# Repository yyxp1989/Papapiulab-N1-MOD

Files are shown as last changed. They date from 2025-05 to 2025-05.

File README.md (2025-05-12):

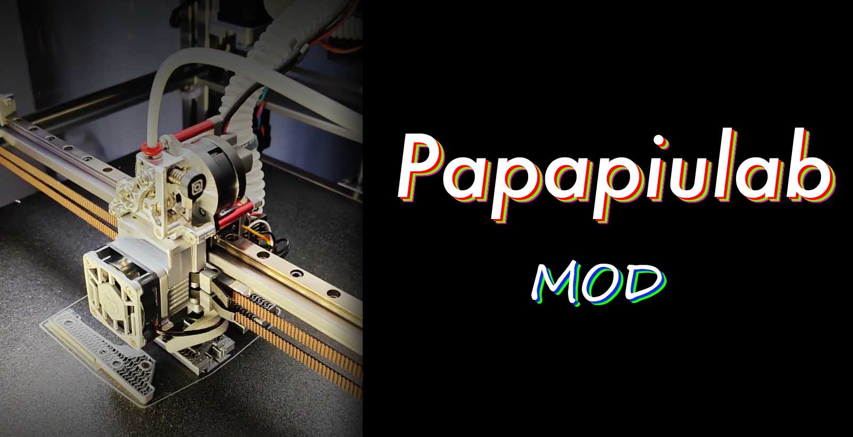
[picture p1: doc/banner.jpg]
papapiulab mod
<p align="center"></a></p>

# Papapiulab N1 MOD
- Papapiulab N1机型定制设计的第三方功能扩展组件
- 如果你喜欢请点击右上星星star收藏^^

# MOD LIST
2025/05/11 [舵机清洁工具](https://github.com/yyxp1989/Papapiulab-N1-MOD/tree/main/Servo_Clear%E8%88%B5%E6%9C%BA%E6%B8%85%E6%B4%81%E5%B7%A5%E5%85%B7)

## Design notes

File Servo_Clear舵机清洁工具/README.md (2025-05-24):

# 准备元件
- 1.微雪树莓派RP2040-Zero [TB](https://item.taobao.com/item.htm?id=658812037267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)
- 2.MG996R或20KG 180度舵机[TB](https://item.taobao.com/item.htm?id=583846405061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)
- 3.轻触开关12x12x5 [TB](https://detail.tmall.com/item.htm?id=14982998994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)
- 4.M3*20~25薄头内六角螺丝<br>
- 5.AWG30左右软电线 红黑黄绿蓝等<br>
- 6.xh2.54 3P公头或插座<br>
- 7.xh2.54 2P连接头<br>
- 8.usb3.0一母二公双头辅助供电线[TB](https://item.taobao.com/item.htm?id=876203533245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)
- 9.25T-6mm全长58mm金属舵机臂 [TB](https://item.taobao.com/item.htm?id=535025013284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)
- 10.A1 mini喷嘴硅胶擦嘴耗材刷[TB](https://item.taobao.com/item.htm?id=821254137525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)
- 11.热熔螺母M3 5个 + M3*8螺丝
- 12.M4*14内六角+4040型材T型或弹片螺母

# RP2040 klipper固件制作
- 1.SSH进入上位机 cd klipper/ <br>
- 2.输入 make clean<br>
- 3.输入 make menuconfig<br>
- 4.选择并调整菜单内容<br>
    - Micro-controller Architecture (Raspberry Pi RP2040/RP235x)  ---><br>
    - Processor model (rp2040)  ---><br>
    - Flash chip (W25Q080 with CLKDIV 2)  ---><br>
    - Bootloader offset (No bootloader)  ---><br>
    - Communication Interface (USBSERIAL)  ---><br>
- 5.按Esc - 退出保存 - Y<br>
- 6.输入make 开始制作固件<br>
- 7.将生成的uf2固件下载至本地 /klipper/out/klipper.uf2<br>
- 8.本地电脑usb连接rp2040 上电后按下boot和rest，弹出移动设备文件夹，将klipper.uf2固件复制到文件夹中会自动刷新固件。<br>

# 硬件连接
- 根据rp2040_setting.cfg文件中的舵机和按钮gpio进行焊接，按钮为下拉触发，其中一引脚焊接至GND，另一脚焊接至对应GPIO<br>
    - 模型文件开源可根据实际需求改进优化
- 按钮gpio初始化为上拉，按下后接通GND下拉触发。<br>
- 为确保舵机启动电流将usb3.0一母二公双头辅助供电线，供电头侧更换为xh2.54 2p,连接至主板常开风扇5v或上位机独立5v3a供电模块
  - 上位机USB电流输出大于0.4a无需额外供电（如树莓派5）
- rp2040 通过一母二公双头辅助供电线，usb数据头连接至上位机，供电头连接至额外5v电源<br>

# RP2040 MCU连接
- 在SSH中输入 ls /dev/serial/by-id/*
- 可见串口设备地址： /dev/serial/by-id/usb-Klipper_rp2040_********-if00 ，并修改rp2040_setting.cfg中rp2040 mcu地址

# 成品图
<p align="center">运行效果</a></p>
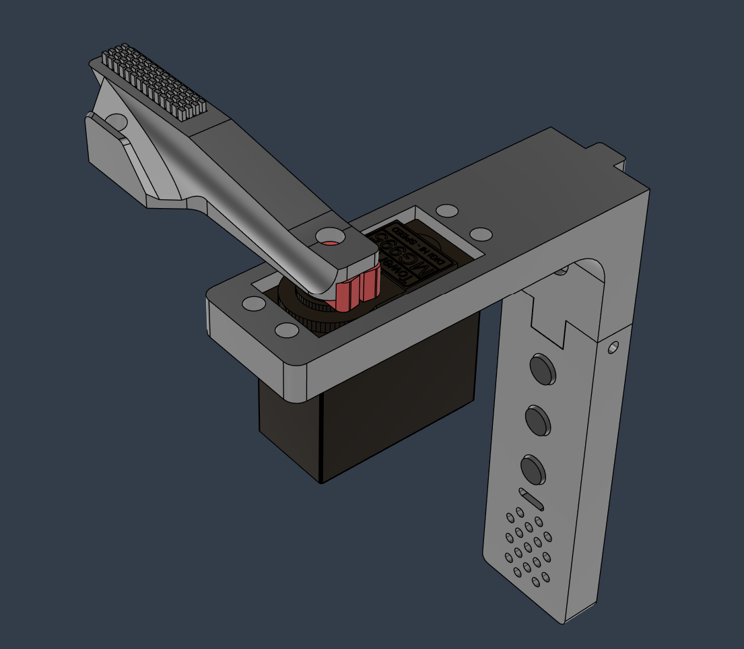
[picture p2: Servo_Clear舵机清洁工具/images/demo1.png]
效果图
<p align="center"></a></p>

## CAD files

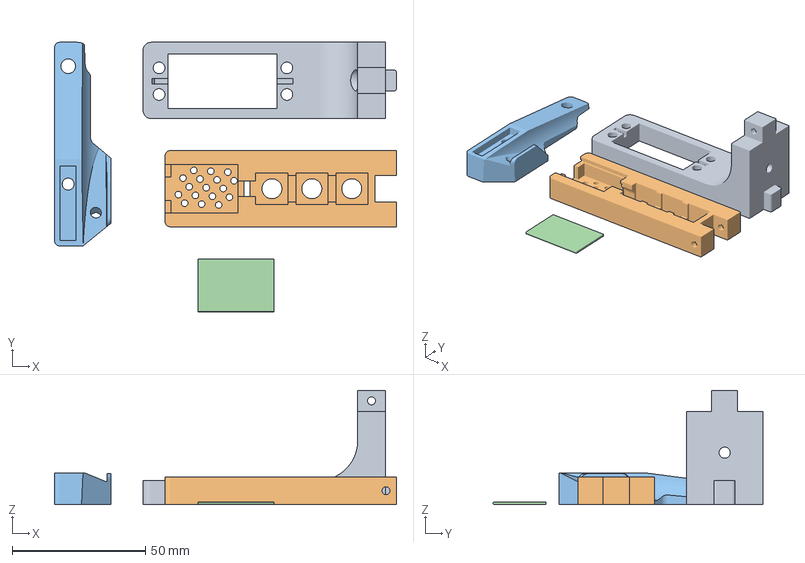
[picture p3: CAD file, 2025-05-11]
Servo_Clear舵机清洁工具/CAD/PRINTOBJ_papapiu_mod_servoClear.3mf
128.6 x 101.3 x 42.9 mm
擦嘴舵机上架
擦嘴舵机下架
擦嘴架
实体1

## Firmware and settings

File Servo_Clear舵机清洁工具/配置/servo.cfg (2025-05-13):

###################
#版本：beta5.0 2025/05/11
#@YY
#功能：通过舵机摇臂伸出清洁头，打印头移动到其上方
#1.打印前来回蹭蹭清除喷嘴余料
#2.在清洁头处进料，余料进簸箕内后擦拭喷嘴。

#注意事项： 确保摇臂在归为前是关闭状态，请将 CLEAR_REST 加入[homing_override]中，在G28之前，避免因舵机故障摇臂未归位撞床的情况！！！！

#清扫前需要归位，避免撞床。Z安全高度20~25！！！！！

#清洁主程序请执行 CLEAR_START

#运行前，请熟悉下列参数和宏

############# 硬件配置 ###################
#见rp2040_setting.cfg

############# 用户设置 ###################
[gcode_macro _User_Servo_Var]
variable_feedfilaments_x:260        #出料点x (螺丝头上方)
variable_feedfilaments_y:14.5       #出料点y (螺丝头上方)

variable_clearblock_x:271           #清洁块起点定位x
variable_clearblock_y:26            #清洁块起点定位y
variable_safe_open_z:20             #伸出清洁头安全Z高度
variable_clearspeed:6500            #擦拭速度 6500/60= 108.3 mm/s
variable_wipe_path:24               #擦拭至末端距离

variable_nozz_hot_temperature:230     #等待喷嘴升至指定温度
variable_nozz_cool_temperature:180    #等待喷嘴降至指定温度

variable_servo_open_angle:100        #伸出清洁头，舵机旋转角度 #重要设置，启用前先不要安装摇臂，空载运行避免撞头！
variable_servo_close_angle:10        #复位清洁头，舵机旋转角度 #重要设置，启用前先不要安装摇臂，空载运行避免撞头！
variable_servo_put_angle:180         #清洁头倒垃圾角度

variable_fancool_ctl: 1             #清扫后开启风扇冷却喷嘴0关/1开
#variable_fancool_delay:8000         #清扫后风扇冷却时间 单位 毫秒（预留）
gcode:

############# 功能区 ###################

[gcode_macro CLEAR_OPEN]
description: 清洁头打开
gcode:
 {% set open_value = printer["gcode_macro _User_Servo_Var"].servo_open_angle %}
 {% set safez = printer["gcode_macro _User_Servo_Var"].safe_open_z %}
 {% set now_z = printer.toolhead.position.z %}
  {% if now_z < 20 %}
    G1 Z{safez} F1800
    {% endif %} 
    SET_SERVO SERVO=my_servo ANGLE={open_value}  #打开

[gcode_macro CLEAR_REST]
description: 清洁头复位
gcode:
  {% set close_value = printer["gcode_macro _User_Servo_Var"].servo_close_angle %}
    SET_SERVO SERVO=my_servo ANGLE={close_value} #复位
   # G4 P1000   #等待时间

[gcode_macro _MOVE_FEED] #进料点位
gcode:
    {% set userservo = printer["gcode_macro _User_Servo_Var"] %}
    G90
    G1 X{userservo.feedfilaments_x} F12000
    G1 Y{userservo.feedfilaments_y} F12000

[gcode_macro _MOVE_CLEAR] #擦块点位
gcode:
    {% set userservo = printer["gcode_macro _User_Servo_Var"] %}
    G90
    G1 X{userservo.clearblock_x} F12000
    G1 Y{userservo.clearblock_y} F12000

[gcode_macro _CLEAR_LOOP] #往复擦拭
gcode:
    {% set userservo = printer["gcode_macro _User_Servo_Var"] %}
    {% set wipe_path_value = printer["gcode_macro _User_Servo_Var"].wipe_path %}
    G90
    {% for _ in range(3) %}
    G1 y{userservo.clearblock_y} F{userservo.clearspeed}
    G1 y{userservo.clearblock_y - userservo.wipe_path} F{userservo.clearspeed}
    G1 x{userservo.clearblock_x + 1} F{userservo.clearspeed}
    G1 y{userservo.clearblock_y} F{userservo.clearspeed}
    G1 x{userservo.clearblock_x - 1} F{userservo.clearspeed}
    G1 y{userservo.clearblock_y - userservo.wipe_path} F{userservo.clearspeed}
    {% endfor %}
    {% for _ in range(3) %}
    G1 y{userservo.clearblock_y} F{userservo.clearspeed}
    G1 y{userservo.clearblock_y - userservo.wipe_path} F{userservo.clearspeed + 8500}
    G1 x{userservo.clearblock_x + 1.5} F{userservo.clearspeed}
    G1 y{userservo.clearblock_y} F{userservo.clearspeed}
    G1 x{userservo.clearblock_x - 1.5} F{userservo.clearspeed}
    G1 y{userservo.clearblock_y - userservo.wipe_path} F{userservo.clearspeed + 8500}
    {% endfor %}
    G1 y{userservo.clearblock_y + 20}

[gcode_macro _NOZZ_HOT] #擦拭温度
gcode:
    {% set userservo = printer["gcode_macro _User_Servo_Var"] %}
    SET_HEATER_TEMPERATURE HEATER=extruder TARGET={userservo.nozz_hot_temperature}
    TEMPERATURE_WAIT SENSOR=extruder MINIMUM={userservo.nozz_hot_temperature} #等待升温
    
[gcode_macro _NOZZ_COOL] #冷却温度
gcode:
    {% set userservo = printer["gcode_macro _User_Servo_Var"] %}
    SET_HEATER_TEMPERATURE HEATER=extruder TARGET=0
   # TEMPERATURE_WAIT SENSOR=extruder MAXIMUM={userservo.nozz_cool_temperature} #等待升温

[gcode_macro _NOZZ_COOL_STOPFAN] #冷却风扇停止
gcode:
    {% set userservo = printer["gcode_macro _User_Servo_Var"] %}
    TEMPERATURE_WAIT SENSOR=extruder MAXIMUM={userservo.nozz_cool_temperature} #等待升温
    M106 S0 #关闭风扇

[gcode_macro _CLEAR_PUT] #倒垃圾
gcode:
    {% set userservo = printer["gcode_macro _User_Servo_Var"] %}
    {% for _ in range(3) %}
    SET_SERVO SERVO=my_servo ANGLE={userservo.servo_put_angle}
    G4 P1200
    SET_SERVO SERVO=my_servo ANGLE={userservo.servo_put_angle - 40}
    {% endfor %}
    CLEAR_REST

[gcode_macro _FAN_COOL] #开启打印散热风扇
gcode:
    {% set userservo = printer["gcode_macro _User_Servo_Var"] %}
    {% if userservo.fancool_ctl == 1 %}
    M106 S250                       #喷头风扇冷却
    #G4 P{userservo.fancool_delay}   #冷却时间
    {% endif %}


[gcode_macro _PULL_BACK] #回抽
gcode:
    G92 E0
    G1 E-5.0 F2000
    G92 E0

[gcode_macro _CLEAR_MSG]
gcode:
  {action_respond_info("喷嘴清洁完成...")}


[gcode_macro CLEAR_START] #开始擦嘴主宏
description: 热端清洁
gcode:
    {% if printer.toolhead.homed_axes != "xyz" %} G28 {% endif %}
    _NOZZ_HOT               #加热喷嘴
    CLEAR_OPEN              #舵机打开
    _MOVE_FEED              #移动至出料点位
    _MOVE_CLEAR             #移动至擦块
    G4 P800                 #给舵机转动时间
    _CLEAR_LOOP             #开擦
    _PULL_BACK              #回抽
     CLEAR_REST             #舵机关闭
    _NOZZ_COOL              #喷嘴冷却
    _FAN_COOL               #打开风扇加速冷却
    HOME_CENTER             #归位
    _NOZZ_COOL_STOPFAN      #等待降温风扇关闭
    _CLEAR_MSG              #完成通知

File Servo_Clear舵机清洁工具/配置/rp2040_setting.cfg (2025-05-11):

[mcu RP2040]
serial: /dev/serial/by-id/usb-Klipper_rp2040_E6625887D3678536-if00

#--------舵机配置
[servo my_servo]
pin: RP2040: gpio13
maximum_servo_angle: 180     #最大角度
minimum_pulse_width: 0.0005  #最小PWM脉宽（见舵机商品介绍页）
maximum_pulse_width: 0.0025  #最大PWM脉宽

#----------RP2040 LED
[neopixel RPLED]
pin: RP2040:gpio16
chain_count: 1
color_order: RGBW

#---------按键
[gcode_button key1]
pin: ^RP2040: gpio4
debounce_delay: 0.15 #最新klipper支持按键防抖
press_gcode:
release_gcode:     
   {action_respond_info("按键1触发")}
   #此行放置需要执行的宏名称
   SET_LED LED=RPLED RED=1 GREEN=0 BLUE=0 WHITE=1   #自定义RP2040 LED颜色

[gcode_button key2]
pin: ^RP2040: gpio6
debounce_delay: 0.1 #最新klipper支持按键防抖
press_gcode:
release_gcode:     
   {action_respond_info("按键2触发")}
   #此行放置需要执行的宏名称
   SET_LED LED=RPLED RED=0 GREEN=1 BLUE=0 WHITE=1 #自定义RP2040 LED颜色

[gcode_button key3]
pin: ^RP2040: gpio8
debounce_delay: 0.15 #最新klipper支持按键防抖
press_gcode:
release_gcode:     
   {action_respond_info("按键3触发")}
   #此行放置需要执行的宏名称
   SET_LED LED=RPLED RED=0 GREEN=0 BLUE=1 WHITE=1 #自定义RP2040 LED颜色

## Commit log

2025-05-11 Create servo_clear
2025-05-11 Create 材料清单
